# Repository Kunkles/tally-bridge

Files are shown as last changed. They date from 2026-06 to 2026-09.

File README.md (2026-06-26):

# ESP32-S3 SmallHD Tally Bridge

**32Thirteen Productions LLC** | DIT Technical Reference

HTTP tally bridge for SmallHD monitors. Receives HTTP GET requests from Bitfocus Companion (or any HTTP client) and triggers GPI tally via optocoupler. Built on the Waveshare ESP32-S3-ETH with W5500 SPI Ethernet and WiFi fallback.

---

## Setup & Deployment

### First Flash

Flash the firmware once — all configuration is done through the browser after that. No need to edit the sketch per unit.

1. Open `tally_light.ino` in Arduino IDE
2. Set board to **ESP32S3 Dev Module**, ESP32 Arduino core v3.x
3. Under **Tools → Erase All Flash Before Sketch Upload → Enabled** (ensures a clean state)
4. Flash the board

### Configure via Web Portal

After flashing, open a browser and go to:

```
http://tally-light.local/
```

or use the IP address shown in the serial monitor if mDNS isn't resolving.

From the portal you can set:

- **Device Hostname** — unique name for this unit (e.g. `tally-cam1`). Becomes the `.local` address.
- **IP Mode** — DHCP or Static. Static reveals fields for IP, Gateway, Subnet, and DNS.
- **WiFi SSID & Password** — fallback network if Ethernet is not connected.

Hit **Save & Reboot** — all settings are stored in flash and survive reboots and reflashes.

### Deploying Multiple Units

1. Flash all units with the same firmware (no per-unit sketch changes needed)
2. Connect each unit and open `http://tally-light.local/` in a browser
3. Set a unique hostname for each unit (e.g. `tally-cam1`, `tally-cam2`)
4. Optionally assign a static IP for each unit for reliable Companion integration
5. Use IP addresses in Companion, not `.local` hostnames — mDNS can be unreliable on managed networks

### Factory Reset

To wipe all saved settings and return a unit to defaults, open the web portal and click **Reset to Defaults** at the bottom of the page. The device reboots as `tally-light` with DHCP enabled.

Alternatively, enable **Erase All Flash Before Sketch Upload** in Arduino IDE before reflashing for a full clean state.

---

## Hardware

| Component | Value |
| :--- | :--- |
| Board | Waveshare ESP32-S3-ETH |
| Ethernet chip | W5500 (SPI) |
| Tally output pin | GPIO18 |
| Test button pin | GPIO3 |
| Optocoupler | NOYITO 1-channel PC817 module |
| ESP32 Arduino core | v3.x required |
| Board selection | ESP32S3 Dev Module |

### W5500 Pin Mapping

| GPIO | Function |
| :--- | :--- |
| GPIO9 | W5500 RST |
| GPIO10 | W5500 INT |
| GPIO11 | SPI MOSI |
| GPIO12 | SPI MISO |
| GPIO13 | SPI CLK |
| GPIO14 | SPI CS |

> **Note:** GPIO18 is the tally output. If a pin is damaged, change `TALLY_PIN` at the top of the sketch — GPIO15 is a confirmed working substitute.

### Optocoupler Wiring

**Input side (ESP32 → Optocoupler):**
| Optocoupler | ESP32 |
| :--- | :--- |
| `+` | GPIO18 |
| `-` | GND |

**Output side (Optocoupler → SmallHD):**
| Optocoupler | SmallHD RJ45 |
| :--- | :--- |
| `VCC` | 3.3V (ESP32) |
| `OUT` | GPI active pin |
| `GND` | GPI ground pin |

> **Tip:** Use an Ethernet screw terminal breakout board (e.g. [Poyiccot RJ45 screw terminal](https://www.amazon.com/dp/B07WKKVZRF)) on the SmallHD end rather than cutting a cable. Direct bare-wire connections are unreliable due to the thin 24AWG solid-core conductors in Ethernet cable. The screw terminal block gives a proper mechanical clamp.

---

## SmallHD OLED 22 GPI Configuration

| Setting | Value |
| :--- | :--- |
| PageOS version required | 6.x or later |
| GPI function | Tally Indicator |
| Polarity | Active High |
| GPI pin | **Pin 7** (not Pin 1) |

> **Important:** Pin 1 does not behave correctly for tally on the OLED 22 — use Pin 7. Polarity is Active High. Tally behavior: open circuit = ON, contact closure = OFF. Verified on hardware running PageOS 6.3.1.
>
> Other SmallHD models in a mixed fleet may require different GPI pin and polarity settings. Bench test each model before deployment.

---

## HTTP API

| Endpoint | Method | Description |
| :--- | :--- | :--- |
| `/` | GET | Web config portal |
| `/config` | GET / POST | Web config portal (same as `/`) |
| `/reset` | POST | Clear all saved settings and reboot to defaults |
| `/tally/on` | GET | Activate tally (GPIO HIGH) |
| `/tally/off` | GET | Deactivate tally (GPIO LOW) |
| `/tally/test` | GET | 1-second tally pulse for testing |
| `/status` | GET | Returns firmware version, IP, interface, IP mode, and tally state |

---

## Bitfocus Companion

Use **Generic: HTTP GET** action.

| Button | URL |
| :--- | :--- |
| Record ON | `http://<device-ip>/tally/on` |
| Record OFF | `http://<device-ip>/tally/off` |
| Test | `http://<device-ip>/tally/test` |
| Status | `http://<device-ip>/status` |

Use static IPs and enter them directly in Companion. mDNS `.local` addresses are convenient for setup but unreliable in production on managed or VLAN'd networks.

---

## Known Issues

- mDNS (`.local`) resolution varies by network — always note the IP as a fallback
- With both Ethernet and WiFi active, the ESP32's mDNS stack can be flaky about which interface it advertises on
- SmallHD GPI behavior differs between monitor models — verify pin and polarity on each model before production deployment

---

*32Thirteen Productions LLC*

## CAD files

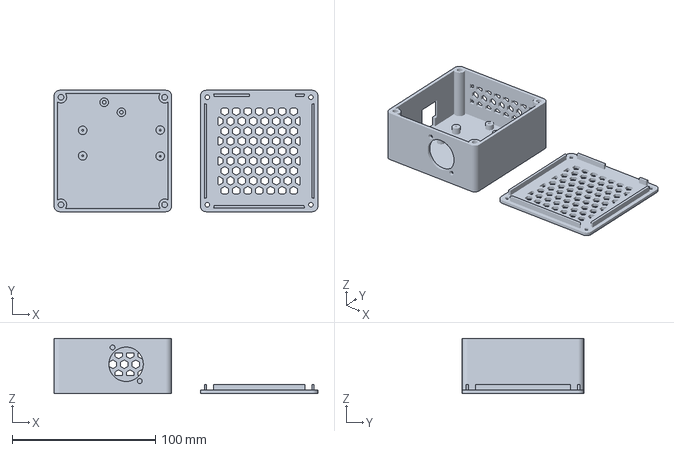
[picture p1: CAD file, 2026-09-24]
enclosure/waveshare_esp32s3_eth_enclosure.3mf
184.2 x 84.8 x 38.4 mm

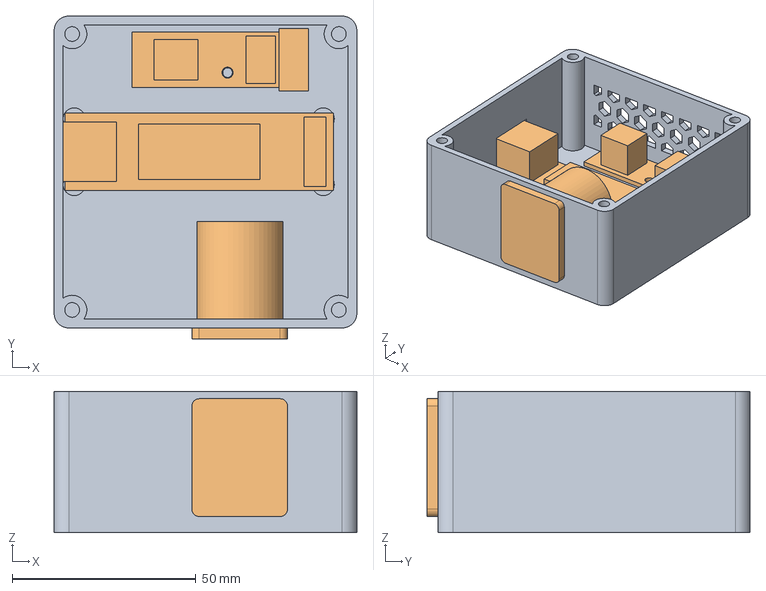
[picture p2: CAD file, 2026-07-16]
enclosure/waveshare_latest.FCStd
82.3 x 87.8 x 38.4 mm

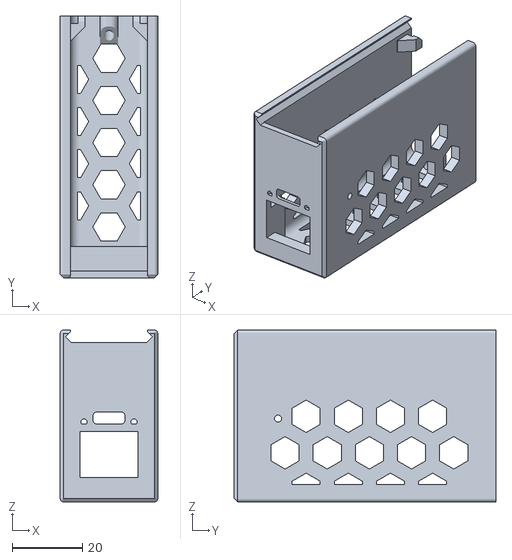
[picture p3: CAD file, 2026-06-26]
enclosure/case-mini.stl
27.8 x 74.5 x 49.0

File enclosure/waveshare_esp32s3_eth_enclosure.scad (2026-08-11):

// =====================================================================
// Waveshare ESP32-S3-ETH two-piece printable enclosure
// + PC817 optocoupler module  + round Ethernet-style panel module
// + honeycomb vents  + M3 brass heat-set inserts
// Native OpenSCAD only. Units = millimeters.
// =====================================================================

// ---------------------------------------------------------------------
// 1. GLOBAL PARAMETERS
// ---------------------------------------------------------------------

// ----- render / display -----
render_part      = "both";   // "base", "lid", or "both"
show_placeholders = true;    // visual modules only, never part of print
$fn = 48;

// ----- enclosure shell -----
wall          = 2.4;
floor_th      = 2.4;
lid_th        = 2.4;
corner_r      = 4;
lid_clearance = 0.35;
wire_clearance = 8;

lip_h    = 4;     // lid locating-lip depth
lip_wall = 1.6;   // lid locating-lip thickness

// ----- ESP32-S3-ETH board (STL-derived footprint) -----
esp32_len            = 72.8; // PCB length per Waveshare drawing (RJ45 overhangs ~2.8 mm more)
esp32_w              = 21;
esp32_h              = 18;    // adjustable, excludes PoE module
esp32_pcb_thickness  = 1.6;

include_poe_clearance = false;
poe_clearance_h       = 24.5;  // only used if include_poe_clearance

// ----- internal cavity -----
// Length defaults to hug the board so the front connector edge (USB-C + RJ45,
// both on the same end) sits near the front wall. Set flush_fit_length
// = false to use the 92 mm starting dimension instead.
// USB-C *and* RJ45 are BOTH on the front board end (stacked) -- only the front
// edge must sit near its wall; the rear end is the free GPIO-header side.
flush_fit_length    = true;
internal_len_manual = 92;
esp32_front_clear   = 0.5;   // front wall inner face -> board connector edge
esp32_rear_clear    = 4.0;   // GPIO-header end -> rear wall (wiring clearance)
internal_len = flush_fit_length
    ? (esp32_front_clear + esp32_len + esp32_rear_clear)
    : internal_len_manual;

// Width raised from the 72 mm start to 80 mm so the 29 mm-deep panel
// module body + board + PC817 + wire clearance all fit side by side.
internal_w = 80;
internal_h = 36;

// ----- derived outer shell -----
outer_len = internal_len + 2*wall;
outer_w   = internal_w   + 2*wall;
base_h    = floor_th + internal_h;   // open-top base height

// ----- ESP32 placement & standoffs -----
esp32_standoff_h = 5;
esp32_standoff_d = 6;
// Board mounting holes measured at 1.66 mm -> M1.6 hardware.
// "screw": standoffs get a 1.25 mm pilot for M1.6 self-tappers. Pilots this
//          small may fuse shut in FDM -- clear with a 1.2-1.3 mm hand drill.
// "pin":   standoffs carry short locating pins instead; board is registered
//          by the pins and captured by the RJ45/USB-C wall openings.
esp32_mount_style = "screw";            // "screw" or "pin"
esp32_hole_d      = 1.66;               // actual board hole (reference)
esp32_pilot_d     = 1.25;               // M1.6 self-tap pilot
esp32_pin_d       = esp32_hole_d - 0.16; // 1.5 -- slip fit, tune after test print
esp32_pin_h       = 2.4;                // proud of the 1.6 mm PCB by ~0.8 mm

esp32_x = wall + esp32_front_clear;     // board min-X (USB-C edge near front)
esp32_y = wall + 35;                    // board min-Y (clears panel body + wiring)
esp32_z = floor_th + esp32_standoff_h;  // PCB underside Z

// Mounting-hole pattern per the official Waveshare dimension drawing
// (ESP32-S3-ETH-details-size.jpg): pairs are NOT symmetric. The rear pair
// sits right at the rear corners, and the two pairs differ in width spacing.
// front/rear = distance of each pair from the FRONT (Ethernet) PCB edge.
esp32_hole_dx_front = 17.78;                // front pair width spacing (c-t-c)
esp32_hole_dx_rear  = 18.25;                // rear pair width spacing (c-t-c)
esp32_hole_front    = 17.07;                // = 72.8 - 54.15 - 1.58
esp32_hole_rear     = esp32_len - 1.58;     // 71.22 -- at the rear corners

// ----- connector stack: BOTH on the FRONT short wall (per case-mini.stl) -----
// The ESP32-S3-ETH carries USB-C + RJ45 on the SAME board end, stacked: RJ45
// low, USB-C ~2.7 mm above it. Opening centres are referenced to the PCB top
// surface so they track standoff height. Sizes/heights measured from the STL.
connector_setback = 0.3;     // tune board fore/aft after test fit

// Vertical stack on the front wall (top -> bottom): RJ45, PCB, USB-C.
// RJ45 sits on TOP of the PCB; USB-C is on the BOTTOM face (hangs below it).
pcb_top_z    = esp32_z + esp32_pcb_thickness; // top surface of the PCB
pcb_bottom_z = esp32_z;                        // bottom surface of the PCB
rj45_center_above_pcb = 6.9;   // RJ45 opening centre above PCB top
usbc_center_below_pcb = 1.6;   // USB-C opening centre below PCB bottom

// USB-C opening (LOWER -- on the underside of the board)
// Sized for the full plug OVERMOLD (USB-IF max ~12.35 x 6.5), not just the
// receptacle, so any brand of cable seats fully. This consumes the thin
// divider strip below the RJ45 opening -- the two merge into one stepped
// cutout, which is fine: that strip was cosmetic, not structural.
usb_c_cutout_w         = 12.6;  // along board width (Y)
usb_c_cutout_h         = 5.8;   // vertical (Z)
usb_c_cutout_clearance = 0.4;
usb_c_cutout_x_offset  = 0;     // lateral nudge along wall (Y)
usb_c_cutout_z         = pcb_bottom_z - usbc_center_below_pcb;
usb_c_relief_w         = 14;    // (unused unless relief re-enabled)
usb_c_relief_h         = 4.5;
usb_c_relief_enabled   = false; // opening is full-size now; no lip to relieve
usb_c_relief_depth     = 1.2;

// RJ45 opening (UPPER -- onboard Ethernet jack, SAME wall, above the board)
rj45_cutout_w         = 16.2;
rj45_cutout_h         = 12.6;
rj45_cutout_clearance = 0.6;
rj45_cutout_x_offset  = 0;
rj45_cutout_z         = pcb_top_z + rj45_center_above_pcb;
rj45_relief_w         = 20;
rj45_relief_h         = 13.8;
rj45_relief_enabled   = true;
rj45_relief_depth     = 1.5;

// ----- PC817 optocoupler module -----
pc817_len             = 40;
pc817_w               = 15;
pc817_pcb_thickness   = 1.6;
pc817_component_h     = 12;
pc817_mount_hole_d    = 3.0;
pc817_standoff_h      = 4;
pc817_standoff_d      = 6;
pc817_standoff_hole_d = 2.6;
pc817_x = wall + (internal_len - pc817_len)/2;   // centered along length
pc817_y = wall + internal_w - pc817_w - 2;       // along the right long wall
pc817_z = floor_th + pc817_standoff_h;

// The real bestep PC817 board carries its two mounting holes on a DIAGONAL,
// offset toward opposite long edges -- NOT on the centerline. Each entry is
// [along board length, across board width] measured from the (pc817_x,pc817_y)
// corner. Render with show_placeholders=true: the standoffs must appear
// directly under the holes punched in the board. MEASURE YOUR BOARD and tune.
pc817_hole1 = [14, 11];   // upper hole, toward one long edge
pc817_hole2 = [26, 4];    // lower hole, toward the other long edge

// ----- round Ethernet-style panel module (separate from onboard RJ45) -----
panel_module_enabled = true;
panel_side = "left";   // "left", "right", "front", or "back"

panel_cutout_d       = 24;
panel_screw_hole_d   = 3.4;
panel_screw_spacing_x = 19;
panel_screw_spacing_y = 23.5;   // vertical pitch per right-hand factory drawing

panel_face_w      = 26;
panel_face_h      = 32;
panel_inner_rect_w = 14.4;
panel_inner_rect_h = 16.2;

panel_depth_total = 31.5;
panel_body_depth  = 29;
panel_body_h      = 23.4;

panel_face_th      = 3;
panel_side_ref_total = 9.1;
panel_rear_ref_th  = 4.7;
panel_rear_block_h = 12;

panel_pos_along = (panel_side=="left" || panel_side=="right")
    ? wall + internal_len*0.62      // X position when on a long wall
    : wall + internal_w*0.5;        // Y position when on a short wall
panel_z = floor_th + internal_h*0.5;

// Notch the lid lip above the panel module: the internal patch cable's
// RJ45 clip (and the fingers pressing it) need the space directly under
// the lid that the lip would otherwise occupy.
panel_lip_notch_enabled = true;
panel_lip_notch_w = panel_face_w + 6;   // span along the wall

// Screw pattern as seen FROM OUTSIDE the wall: [horizontal, vertical] offset
// from the bore centre, with right = + and up = +. Diagonal pair at 19 mm
// horizontal x 23.5 mm vertical. Swap the signs on a row to flip the diagonal.
panel_screw_holes = [
    [ panel_screw_spacing_x/2,  panel_screw_spacing_y/2],   // upper-right (outside view)
    [-panel_screw_spacing_x/2, -panel_screw_spacing_y/2]    // lower-left  (outside view)
];

// ----- M3 brass heat-set inserts (Ruthex M3 x 5.7) -----
insert_len        = 5.7;
insert_outer_d    = 4.6;
insert_hole_d     = 4.0;
insert_hole_depth = 5.8;
insert_min_wall   = 1.6;

boss_d     = 8;
boss_inset = boss_d/2 - 1.5;   // pull bosses into corners so they fuse to walls
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

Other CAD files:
enclosure/waveshare_esp32s3_eth_enclosurev3.stl
enclosure/waveshare_esp32s3_eth_enclosure.stl

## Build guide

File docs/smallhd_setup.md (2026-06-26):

# SmallHD GPI Tally Setup

## OLED 22 (Verified)

PageOS 6.x or later required.

**GPI Settings:**
| Setting | Value |
| :--- | :--- |
| GPI Function | Tally Indicator |
| Polarity | Active High |
| GPI Pin | **Pin 7** |

> **Pin 1 does not work for tally on the OLED 22.** Use Pin 7. This differs from what some documentation states — verified on hardware.

**Behavior:**
- Open circuit (no signal) = Tally ON
- Contact closure = Tally OFF

This is why the firmware logic is inverted — `HIGH` on the optocoupler output opens the circuit (tally on), `LOW` closes it (tally off).

---

## Other SmallHD Models

GPI pin assignment and polarity vary by model. Bench test each model before production deployment. Settings that work on the OLED 22 may not apply to other monitors in a mixed fleet.

---

## RJ45 Pinout Reference (T568B)

| Pin | Color | Used for tally |
| :--- | :--- | :--- |
| 1 | White/Orange | — |
| 2 | Orange | — |
| 3 | White/Green | — |
| 4 | Blue | Check monitor docs |
| 5 | White/Blue | Check monitor docs |
| 6 | Green | — |
| 7 | White/Brown | **GPI active (OLED 22)** |
| 8 | Brown | GPI ground |

> Use a screw terminal RJ45 breakout board for reliable connections. Bare Ethernet wire is 24AWG solid-core and makes poor contact when inserted directly into terminals.

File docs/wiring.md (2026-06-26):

# Wiring Reference

## ESP32 to Optocoupler

| Optocoupler Pin | ESP32 Pin |
| :--- | :--- |
| `+` (input anode) | GPIO18 (TALLY_PIN) |
| `-` (input cathode) | GND |

The optocoupler input side is driven directly from the GPIO pin. No current-limiting resistor is needed for the NOYITO PC817 module as it has one built in.

---

## Optocoupler to SmallHD RJ45

| Optocoupler Pin | Destination |
| :--- | :--- |
| `VCC` | 3.3V (ESP32) |
| `OUT` | SmallHD RJ45 Pin 7 (GPI active) |
| `GND` | SmallHD RJ45 Pin 8 (GPI ground) |

---

## W5500 Ethernet Module to ESP32-S3

On the Waveshare ESP32-S3-ETH these are internally wired. Listed here for reference:

| W5500 | GPIO |
| :--- | :--- |
| RST | GPIO9 |
| INT | GPIO10 |
| MOSI | GPIO11 |
| MISO | GPIO12 |
| CLK | GPIO13 |
| CS | GPIO14 |

---

## Test Button

| Button Pin | ESP32 Pin |
| :--- | :--- |
| One side | GPIO3 |
| Other side | GND |

GPIO3 is configured with `INPUT_PULLUP`. Press triggers a 1-second tally test pulse.

---

## Notes

- If GPIO18 is damaged, change `TALLY_PIN` to another free GPIO (GPIO15 confirmed working substitute)
- Use a [screw terminal RJ45 breakout](https://www.amazon.com/dp/B07WKKVZRF) on the SmallHD end — direct bare-wire connections with cut Ethernet cable are unreliable
- Keep the optocoupler output wires short to avoid noise pickup

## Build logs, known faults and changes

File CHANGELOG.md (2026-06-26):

# Changelog

All notable changes to the Tally Bridge firmware.

---

## v5.8 — 2026-06-25

- Initial GitHub release — firmware reorganized into `firmware/tally_bridge/` with enclosure and docs
- No functional firmware changes from v5.6

## v5.7

- Internal revision (changes not separately documented)

## v5.6 — 2026-05-30

- Tally control card added to web portal
- Live indicator (red dot + label) reflects current tally state
- ON / OFF buttons toggle tally instantly via fetch() — no page reload
- Indicator updates dynamically in the browser without a refresh

## v5.5 — 2026-05-30

- Tally output pin configurable via web portal
- Pin field is locked by default with a checkbox to unlock — prevents accidental changes
- Active pin shown in status card and serial output on boot
- `DEFAULT_TALLY_PIN` replaces hardcoded constant; active pin loaded from flash at boot

## v5.4 — 2026-05-30

- Static IP support — IP, Gateway, Subnet, DNS configurable via web portal
- IP mode (DHCP/Static) shown in status card and `/status` endpoint
- Factory Reset button added to web portal — clears all NVS settings and reboots to defaults
- Static fields show/hide dynamically based on IP mode selection

## v5.3 — 2026-05-30

- Added web config portal at `/` and `/config`
- Hostname configurable at runtime via browser — no reflash needed
- WiFi SSID and password configurable via web portal
- All settings persisted in flash using `Preferences` library
- `prefs.end()` called before reboot to ensure flash commit
- `FW_VERSION` constant added — drives version string in page header and `/status`
- Default hostname changed to `tally-light`

## v5.2

- Web config portal introduced for hostname management
- `Preferences` library added for flash storage
- Root `/` now serves config page

## v5.1 — Initial release

- ESP32-S3 + W5500 SPI Ethernet with WiFi fallback
- 15-second network timeout on boot
- mDNS hostname via `MDNS.begin()`
- HTTP endpoints: `/tally/on`, `/tally/off`, `/tally/test`, `/status`
- Physical test button on GPIO3 with internal pull-up
- `HOSTNAME` variable extracted to top of file
- Serial output prints actual hostname in mDNS URLs
- Tested on Waveshare ESP32-S3-ETH with SmallHD OLED 22, PageOS 6.3.1
- ESP32 Arduino core v3.3.8

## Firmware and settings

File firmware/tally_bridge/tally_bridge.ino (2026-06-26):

#include <ETH.h>
#include <Network.h>
#include <WebServer.h>
#include <ESPmDNS.h>
#include <WiFi.h>
#include <Preferences.h>

// --- DEFAULT TALLY PIN (can be overridden via web portal) ---
const int DEFAULT_TALLY_PIN = 18;

// --- BUTTON PIN ---
#define BUTTON_PIN 3

// --- W5500 SPI ETHERNET PINS ---
#define ETH_MOSI_PIN   11
#define ETH_MISO_PIN   12
#define ETH_SCK_PIN    13
#define ETH_CS_PIN     14
#define ETH_INT_PIN    10
#define ETH_RST_PIN     9
#define ETH_PHY_ADDR    1

// --- FIRMWARE VERSION ---
const char* FW_VERSION = "v5.8";

// --- DEFAULTS (used only on first boot, overridden by web portal) ---
const char* DEFAULT_HOSTNAME = "tally-light";
const char* DEFAULT_WIFI_SSID = "YOUR_SSID";
const char* DEFAULT_WIFI_PASS = "YOUR_PASSWORD";

Preferences prefs;
String activeHostname;
String activeSSID;
String activePass;
String ipMode;          // "dhcp" or "static"
IPAddress staticIP, staticGW, staticSN, staticDNS;
int activePin;

WebServer server(80);
bool eth_connected = false;
bool wifi_connected = false;

// -----------------------------------------------------------------------

void NetworkEvent(arduino_event_id_t event) {
  switch (event) {
    case ARDUINO_EVENT_ETH_START:
      ETH.setHostname(activeHostname.c_str());
      if (ipMode == "static")
        ETH.config(staticIP, staticGW, staticSN, staticDNS);
      break;
    case ARDUINO_EVENT_ETH_CONNECTED:
      Serial.println("Ethernet cable connected");
      break;
    case ARDUINO_EVENT_ETH_GOT_IP:
      Serial.print("Ethernet IP: ");
      Serial.println(ETH.localIP().toString());
      eth_connected = true;
      break;
    case ARDUINO_EVENT_ETH_DISCONNECTED:
      Serial.println("Ethernet disconnected");
      eth_connected = false;
      break;
    case ARDUINO_EVENT_ETH_STOP:
      Serial.println("Ethernet stopped");
      eth_connected = false;
      break;
    case ARDUINO_EVENT_WIFI_STA_GOT_IP:
      Serial.print("WiFi IP: ");
      Serial.println(WiFi.localIP().toString());
      wifi_connected = true;
      break;
    case ARDUINO_EVENT_WIFI_STA_DISCONNECTED:
      Serial.println("WiFi disconnected");
      wifi_connected = false;
      break;
    default:
      break;
  }
}

void triggerTest() {
  digitalWrite(activePin, HIGH);
  delay(1000);
  digitalWrite(activePin, LOW);
  Serial.println("TALLY TEST");
}

// -----------------------------------------------------------------------

String buildConfigPage(String message = "") {
  String ip     = eth_connected ? ETH.localIP().toString() : WiFi.localIP().toString();
  String iface  = eth_connected ? "Ethernet" : "WiFi";
  String tstate = digitalRead(activePin) ? "ON" : "OFF";
  bool   isStatic = (ipMode == "static");

  String html = R"rawliteral(
<!DOCTYPE html>
<html>
<head>
  <meta charset="UTF-8">
  <meta name="viewport" content="width=device-width, initial-scale=1">
  <title>Tally Bridge Config</title>
  <style>
    body { font-family: sans-serif; background: #1a1a1a; color: #eee;
           max-width: 480px; margin: 40px auto; padding: 0 20px; }
    h1   { color: #ff4444; font-size: 1.4em; margin-bottom: 4px; }
    .sub { color: #888; font-size: 0.85em; margin-bottom: 24px; }
    .card { background: #2a2a2a; border-radius: 8px; padding: 20px; margin-bottom: 16px; }
    .card h2 { margin: 0 0 12px; font-size: 0.85em; color: #888;
               text-transform: uppercase; letter-spacing: 0.08em; }
    .stat { display: flex; justify-content: space-between; margin: 6px 0; font-size: 0.95em; }
    .stat span:last-child { color: #fff; font-weight: bold; }
    label { display: block; margin-top: 12px; margin-bottom: 6px; color: #aaa; font-size: 0.9em; }
    label:first-of-type { margin-top: 0; }
    input[type=text],
    input[type=password] { width: 100%; box-sizing: border-box; padding: 10px;
                           background: #333; border: 1px solid #444; border-radius: 6px;
                           color: #fff; font-size: 1em; }
    input[type=text]:focus,
    input[type=password]:focus { outline: none; border-color: #ff4444; }
    .radio-group { display: flex; gap: 12px; margin: 4px 0 8px; }
    .radio-group label { margin: 0; display: flex; align-items: center; gap: 6px;
                         color: #eee; font-size: 1em; cursor: pointer; }
    button { width: 100%; margin-top: 16px; padding: 12px; background: #ff4444;
             color: #fff; border: none; border-radius: 6px; font-size: 1em; cursor: pointer; }
    button:hover { background: #cc3333; }
    .msg  { background: #2a4a2a; border: 1px solid #4a7a4a; border-radius: 6px;
            padding: 10px 14px; margin-bottom: 16px; color: #88cc88; font-size: 0.9em; }
    .err  { background: #4a2a2a; border: 1px solid #7a4a4a; border-radius: 6px;
            padding: 10px 14px; margin-bottom: 16px; color: #cc8888; font-size: 0.9em; }
    .note { color: #666; font-size: 0.8em; margin-top: 8px; }
    .divider { border: none; border-top: 1px solid #3a3a3a; margin: 16px 0; }
    #staticFields { display: none; }
    .lock-row { display: flex; align-items: center; gap: 10px; }
    .lock-row input[type=text] { flex: 1; }
    .lock-row label { margin: 0; display: flex; align-items: center; gap: 5px;
                      color: #888; font-size: 0.85em; white-space: nowrap; cursor: pointer; }
    input:disabled { opacity: 0.4; cursor: not-allowed; }
    .tally-indicator { display: flex; align-items: center; gap: 14px; margin-bottom: 16px; }
    .tally-dot { width: 48px; height: 48px; border-radius: 50%; background: #333;
                 transition: background 0.2s; flex-shrink: 0; }
    .tally-dot.on { background: #ff2222; box-shadow: 0 0 16px #ff2222aa; }
    .tally-label { font-size: 1.4em; font-weight: bold; color: #555; }
    .tally-label.on { color: #ff4444; }
    .btn-row { display: flex; gap: 10px; }
    .btn-row button { margin-top: 0; }
    .btn-active   { background: #ff4444 !important; }
    .btn-active:hover { background: #cc3333 !important; }
    .btn-inactive { background: #444 !important; }
    .btn-inactive:hover { background: #555 !important; }
  </style>
</head>
<body>
  <h1>&#9679; Tally Bridge</h1>
  <div class="sub">SmallHD Tally Controller</div>
)rawliteral";

  html += "  <div class=\"sub\" style=\"margin-top:-18px; margin-bottom:20px;\">Firmware " + String(FW_VERSION) + "</div>";

  if (message.length() > 0) {
    bool isErr = message.startsWith("&#10007;");
    html += "<div class=\"" + String(isErr ? "err" : "msg") + "\">" + message + "</div>";
  }

  // Status card
  html += "<div class=\"card\"><h2>Status</h2>";
  html += "<div class=\"stat\"><span>Device Name</span><span>" + activeHostname + "</span></div>";
  html += "<div class=\"stat\"><span>Interface</span><span id=\"statusIface\">" + iface + "</span></div>";
  html += "<div class=\"stat\"><span>IP Address</span><span id=\"statusIP\">" + ip + "</span></div>";
  html += "<div class=\"stat\"><span>IP Mode</span><span>" + ipMode + "</span></div>";
  html += "<div class=\"stat\"><span>Tally Pin</span><span>GPIO" + String(activePin) + "</span></div>";
  html += "<div class=\"stat\"><span>Tally State</span><span id=\"statusTally\">" + tstate + "</span></div>";
  html += "</div>";

  // Tally control card
  String dotClass   = (tstate == "ON") ? " on" : "";
  String labelClass = (tstate == "ON") ? " on" : "";
  html += "<div class=\"card\"><h2>Tally Control</h2>";
  html += "<div class=\"tally-indicator\">";
  html += "  <div class=\"tally-dot" + dotClass + "\" id=\"tallyDot\"></div>";
  html += "  <span class=\"tally-label" + labelClass + "\" id=\"tallyLabel\">TALLY " + tstate + "</span>";
  html += "</div>";
  String onClass  = (tstate == "ON")  ? "btn-active" : "btn-inactive";
  String offClass = (tstate == "OFF") ? "btn-active" : "btn-inactive";
  html += "<div class=\"btn-row\">";
  html += "  <button id=\"btnOn\"  class=\"" + onClass  + "\" onclick=\"setTally('on')\">ON</button>";
  html += "  <button id=\"btnOff\" class=\"" + offClass + "\" onclick=\"setTally('off')\">OFF</button>";
  html += "</div></div>";

  // Config card
  html += R"rawliteral(
  <div class="card">
    <h2>Configure</h2>
    <form method="POST" action="/config">

      <label>Device Hostname</label>
)rawliteral";

  html += "      <input type=\"text\" name=\"hostname\" id=\"hostnameField\" value=\"" + activeHostname
        + "\" maxlength=\"32\" pattern=\"[a-zA-Z0-9\\-]+\" oninput=\"updatePreview()\" required>";
  html += "      <p class=\"note\">Letters, numbers, and hyphens only.</p>";
  html += "      <p class=\"note\" style=\"color:#aaa;\">URL: <span id=\"urlPreview\" style=\"color:#fff;\">http://" + activeHostname + ".local/</span></p>";

  html += "      <label>Tally Output Pin</label>";
  html += "      <div class=\"lock-row\">";
  html += "        <input type=\"text\" name=\"pin\" id=\"pinField\" value=\"" + String(activePin)
        + "\" maxlength=\"2\" pattern=\"[0-9]+\" disabled>";
  html += "        <label><input type=\"checkbox\" onchange=\"document.getElementById('pinField').disabled=!this.checked\"> Unlock to edit</label>";
  html += "      </div>";
  html += "      <p class=\"note\">Default is GPIO18. Only change if that pin is damaged — GPIO15 is a confirmed substitute. Locked by default to prevent accidental changes.</p>";

  html += "      <hr class=\"divider\">";

  // IP mode radios
  html += "      <label>IP Mode</label>";
  html += "      <div class=\"radio-group\">";
  html += "        <label><input type=\"radio\" name=\"ipmode\" value=\"dhcp\""
        + String(!isStatic ? " checked" : "") + " onchange=\"toggleStatic(this)\"> DHCP</label>";
  html += "        <label><input type=\"radio\" name=\"ipmode\" value=\"static\""
        + String(isStatic ? " checked" : "") + " onchange=\"toggleStatic(this)\"> Static</label>";
  html += "      </div>";

  // Static IP fields — pre-filled if currently in static mode
  html += "      <div id=\"staticFields\">";
  html += "        <label>IP Address</label>";
  html += "        <input type=\"text\" name=\"ip\" value=\"" + staticIP.toString() + "\" placeholder=\"192.168.1.100\">";
  html += "        <label>Gateway</label>";
  html += "        <input type=\"text\" name=\"gw\" value=\"" + staticGW.toString() + "\" placeholder=\"192.168.1.1\">";
  html += "        <label>Subnet Mask</label>";
  html += "        <input type=\"text\" name=\"sn\" value=\"" + staticSN.toString() + "\" placeholder=\"255.255.255.0\">";
  html += "        <label>DNS Server</label>";
  html += "        <input type=\"text\" name=\"dns\" value=\"" + staticDNS.toString() + "\" placeholder=\"8.8.8.8\">";
  html += "      </div>";

  html += "      <hr class=\"divider\">";

  html += "      <label>WiFi SSID</label>";
  html += "      <input type=\"text\" name=\"ssid\" value=\"" + activeSSID + "\" maxlength=\"64\">";
  html += "      <label>WiFi Password</label>";
  html += "      <input type=\"password\" name=\"pass\" placeholder=\"leave blank to keep current\" maxlength=\"64\">";
  html += "      <p class=\"note\">Only used if Ethernet is not connected.</p>";

  // Show static fields immediately if currently in static mode, else JS handles it
  String initScript = isStatic
    ? "document.getElementById('staticFields').style.display='block';"
    : "";

  html += R"rawliteral(
      <button type="submit">Save &amp; Reboot</button>
    </form>
  </div>

  <div class="card">
    <h2>Factory Reset</h2>
    <p class="note" style="margin:0 0 12px;">Clears all saved settings and reboots. Device will return to firmware defaults.</p>
    <form method="POST" action="/reset" onsubmit="return confirm('Reset all settings to factory defaults?')">
      <button type="submit" style="background:#555;">Reset to Defaults</button>
    </form>
  </div>
  <script>
    function updatePreview() {
      var name = document.getElementById('hostnameField').value || 'tally-light';
      document.getElementById('urlPreview').textContent = 'http://' + name + '.local/';
    }
    function pollStatus() {
      fetch('/status')
        .then(function(r) { return r.text(); })
        .then(function(txt) {
          var on = txt.indexOf('Tally: ON') !== -1;
          // Status card
          var st = document.getElementById('statusTally');
          if (st) st.textContent = on ? 'ON' : 'OFF';
          var ip = txt.match(/IP: ([^\s|]+)/);
          if (ip) { var el = document.getElementById('statusIP'); if (el) el.textContent = ip[1]; }
          var iface = txt.indexOf('Ethernet') !== -1 ? 'Ethernet' : 'WiFi';
          var fi = document.getElementById('statusIface'); if (fi) fi.textContent = iface;
          // Tally control card
          document.getElementById('tallyDot').className   = 'tally-dot'   + (on ? ' on' : '');
          document.getElementById('tallyLabel').className = 'tally-label' + (on ? ' on' : '');
          document.getElementById('tallyLabel').textContent = 'TALLY ' + (on ? 'ON' : 'OFF');
          document.getElementById('btnOn').className  = on ? 'btn-active' : 'btn-inactive';
          document.getElementById('btnOff').className = on ? 'btn-inactive' : 'btn-active';
        })
        .catch(function() {}); // silently ignore if device is busy
    }
    setInterval(pollStatus, 3000);
    function toggleStatic(el) {
      document.getElementById('staticFields').style.display =
        el.value === 'static' ? 'block' : 'none';
    }
    function setTally(state) {
      fetch('/tally/' + state)
        .then(() => {
          var on = state === 'on';
          document.getElementById('tallyDot').className   = 'tally-dot'   + (on ? ' on' : '');
          document.getElementById('tallyLabel').className = 'tally-label' + (on ? ' on' : '');
          document.getElementById('tallyLabel').textContent = 'TALLY ' + state.toUpperCase();
          document.getElementById('btnOn').className  = on ? 'btn-active' : 'btn-inactive';
          document.getElementById('btnOff').className = on ? 'btn-inactive' : 'btn-active';
        });
    }
)rawliteral";

  html += "    " + initScript;
  html += R"rawliteral(
  </script>
</body>
</html>
)rawliteral";

  return html;
}

// -----------------------------------------------------------------------

void setup() {
  Serial.begin(115200);
  delay(500);

  // Load all settings from flash — fall back to defaults on first boot
  prefs.begin("tally", false);
  activeHostname = prefs.getString("hostname", DEFAULT_HOSTNAME);
  activeSSID     = prefs.getString("ssid",     DEFAULT_WIFI_SSID);
  activePass     = prefs.getString("pass",     DEFAULT_WIFI_PASS);
  ipMode         = prefs.getString("ipmode",   "dhcp");
  activePin      = prefs.getInt("pin", DEFAULT_TALLY_PIN);

  staticIP.fromString(prefs.getString("ip",  "192.168.1.100"));
  staticGW.fromString(prefs.getString("gw",  "192.168.1.1"));
  staticSN.fromString(prefs.getString("sn",  "255.255.255.0"));
  staticDNS.fromString(prefs.getString("dns", "8.8.8.8"));

  Serial.println("Hostname:  " + activeHostname);
  Serial.println("IP Mode:   " + ipMode);
  Serial.println("Tally Pin: GPIO" + String(activePin));
  if (ipMode == "static")
    Serial.println("Static IP: " + staticIP.toString());

  pinMode(activePin, OUTPUT);
  digitalWrite(activePin, LOW); // default LOW — tally OFF

  pinMode(BUTTON_PIN, INPUT_PULLUP);

  Network.onEvent(NetworkEvent);

  ETH.begin(ETH_PHY_W5500, ETH_PHY_ADDR,
            ETH_CS_PIN, ETH_INT_PIN, ETH_RST_PIN,
            SPI2_HOST, ETH_SCK_PIN, ETH_MISO_PIN, ETH_MOSI_PIN);

  WiFi.setHostname(activeHostname.c_str());
  if (ipMode == "static")
    WiFi.config(staticIP, staticGW, staticSN, staticDNS);
  WiFi.begin(activeSSID.c_str(), activePass.c_str());

  Serial.println("Waiting for network...");
  unsigned long start = millis();
  while (!eth_connected && !wifi_connected) {
    delay(100);
    if (millis() - start > 15000) {
      Serial.println("Network timeout — check connections");
      break;
    }
  }

  if (eth_connected) Serial.println("Connected via Ethernet.");
  if (wifi_connected) Serial.println("Connected via WiFi.");

  MDNS.begin(activeHostname.c_str());
  MDNS.addService("tally", "tcp", 80);

  // --- Config portal ---
  server.on("/", HTTP_GET, []() {
    server.send(200, "text/html", buildConfigPage());
  });

  server.on("/config", HTTP_GET, []() {
    server.send(200, "text/html", buildConfigPage());
  });

  server.on("/config", HTTP_POST, []() {
    bool valid = server.hasArg("hostname") && server.arg("hostname").length() > 0;
    if (!valid) {
      server.send(400, "text/html", buildConfigPage("&#10007; Invalid hostname — please try again."));
      return;
    }

    prefs.putString("hostname", server.arg("hostname"));

    if (server.hasArg("pin") && server.arg("pin").length() > 0)
      prefs.putInt("pin", server.arg("pin").toInt());

    if (server.hasArg("ssid") && server.arg("ssid").length() > 0)
      prefs.putString("ssid", server.arg("ssid"));
    if (server.hasArg("pass") && server.arg("pass").length() > 0)
      prefs.putString("pass", server.arg("pass"));

    String newMode = server.hasArg("ipmode") ? server.arg("ipmode") : "dhcp";
    prefs.putString("ipmode", newMode);

    if (newMode == "static") {
      if (server.hasArg("ip"))  prefs.putString("ip",  server.arg("ip"));
      if (server.hasArg("gw"))  prefs.putString("gw",  server.arg("gw"));
      if (server.hasArg("sn"))  prefs.putString("sn",  server.arg("sn"));
      if (server.hasArg("dns")) prefs.putString("dns", server.arg("dns"));
    }

    server.send(200, "text/html",
      buildConfigPage("&#10003; Settings saved — rebooting now..."));
    delay(2000);
    prefs.end(); // flush to flash before reboot
    ESP.restart();
  });

  // --- Factory reset ---
  server.on("/reset", HTTP_POST, []() {
    prefs.clear();
    server.send(200, "text/html", buildConfigPage("&#10003; Settings cleared — rebooting to defaults..."));
    delay(2000);
    prefs.end();
    ESP.restart();
  });

  // --- Tally endpoints ---
  server.on("/tally/on", HTTP_GET, []() {
    digitalWrite(activePin, HIGH);
    server.send(200, "text/plain", "Tally ON");
    Serial.println("TALLY ON");
  });

  server.on("/tally/off", HTTP_GET, []() {
    digitalWrite(activePin, LOW);
    server.send(200, "text/plain", "Tally OFF");
    Serial.println("TALLY OFF");
  });

  server.on("/tally/test", HTTP_GET, []() {
    server.send(200, "text/plain", "Tally TEST");
    triggerTest();
  });

  server.on("/status", HTTP_GET, []() {
    String ip    = eth_connected ? ETH.localIP().toString() : WiFi.localIP().toString();
    String iface = eth_connected ? "Ethernet" : "WiFi";
    String s     = digitalRead(activePin) ? "ON" : "OFF";
    server.send(200, "text/plain",
      "Tally Bridge " + String(FW_VERSION) + " | " + iface + " IP: " + ip
      + " | Mode: " + ipMode + " | Tally: " + s + " | Host: " + activeHostname);
  });

  server.begin();

  String ip = eth_connected ? ETH.localIP().toString() : WiFi.localIP().toString();
  Serial.println("HTTP server running.");
  Serial.println("  CONFIG: http://" + activeHostname + ".local/");
  Serial.println("  ON:     http://" + activeHostname + ".local/tally/on");
  Serial.println("  OFF:    http://" + activeHostname + ".local/tally/off");
  Serial.println("  TEST:   http://" + activeHostname + ".local/tally/test");
  Serial.println("  STATUS: http://" + activeHostname + ".local/status");
  Serial.println("  IP:     http://" + ip);
}

void loop() {
  server.handleClient();

  if (digitalRead(BUTTON_PIN) == LOW) {
    triggerTest();
    while (digitalRead(BUTTON_PIN) == LOW); // wait for release
  }
}

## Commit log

2026-06-26 feat: initial working firmware and enclosure v5.8
    ESP32-S3 tally bridge for SmallHD monitors — Ethernet + WiFi, web config
    portal, static IP, mDNS, optocoupler GPI output. Parametric OpenSCAD
    enclosure included. Tested on Waveshare ESP32-S3-ETH + SmallHD OLED 22.
    [case-mini.stl, waveshare_esp32s3_eth_enclosure.scad, waveshare_esp32s3_eth_enclosure.stl]
2026-07-16 enclosure: update STL and add FreeCAD source file
    [waveshare_esp32s3_eth_enclosure.stl, waveshare_latest.FCStd]
2026-07-16 enclosure: fix ESP32 standoffs per official Waveshare dimension drawing
    The rear mounting-hole pair was assumed symmetric with the front pair
    (55.5 mm from front edge) but actually sits at the rear corners
    (71.22 mm). Pairs also differ in width spacing: 17.78 mm front,
    18.25 mm rear. Board holes measured 1.66 mm -- too small for screws
    into printed pilots -- so standoffs now carry 1.5 mm locating pins
    instead of screw pilot holes. Board length corrected 73 -> 72.8 mm.
    Source: ESP32-S3-ETH-details-size.jpg (Waveshare product drawing),
    hole diameter measured on hardware.
    [waveshare_esp32s3_eth_enclosure.scad, waveshare_esp32s3_eth_enclosure.stl]
2026-07-16 enclosure: default to M1.6 screw mounting with pin option
    esp32_mount_style selects "screw" (1.25 mm pilot for M1.6 self-tappers,
    clear with a hand drill if the print fuses it) or "pin" (locating pins,
    no screws). Default is screw per printed-fit preference.
    [waveshare_esp32s3_eth_enclosure.scad, waveshare_esp32s3_eth_enclosure.stl]
2026-07-16 enclosure: render lid in print orientation
    Lid now sits on the build plate at z=0, outer face down, lip up --
    no supports and no reorientation needed in the slicer. Applies to both
    "lid" and "both" render modes; assembly-position module unchanged.
    [waveshare_esp32s3_eth_enclosure.scad, waveshare_esp32s3_eth_enclosure.stl]
2026-07-24 enclosure: open USB-C cutout to full overmold size, drop the relief lip
    10.3x4.0 receptacle-sized hole -> 13.4x6.6 so any brand's plug overmold
    passes through the wall and seats fully. The 1.2 mm cosmetic divider
    strip below the RJ45 opening is consumed; the two openings merge into
    one stepped cutout. Relief inset removed -- nothing left to relieve.
    [waveshare_esp32s3_eth_enclosure.scad, waveshare_esp32s3_eth_enclosure.stl]
2026-08-11 enclosure: restore lid-lip notch over the panel Ethernet coupler
    The internal patch plug's release clip and the upper panel screw sit
    just under the lip; notch the lip (panel_face_w + 6 wide, full lip
    height) on whichever wall panel_side selects. The notch existed in an
    older FreeCAD export but at a misplaced position; now parametric and
    centered on the coupler.
    [waveshare_esp32s3_eth_enclosure.scad, waveshare_esp32s3_eth_enclosure.stl, waveshare_esp32s3_eth_enclosurev3.stl]
2026-09-24 enclosure: binary STL export + Bambu Studio project file
    Swap the ASCII STL for a binary export of identical geometry (same
    184.2 x 84.8 x 38.4 bbox, volume within 1 mm3) -- 1.5 MB -> 457 KB.
    Add the Bambu Studio project: X1 Carbon / 0.4 nozzle, 0.12mm Fine,
    ABS, 2 walls, 15% infill, no supports, textured plate. Both parts
    laid out on one plate in print orientation.
    [waveshare_esp32s3_eth_enclosure.3mf, waveshare_esp32s3_eth_enclosure.stl]
